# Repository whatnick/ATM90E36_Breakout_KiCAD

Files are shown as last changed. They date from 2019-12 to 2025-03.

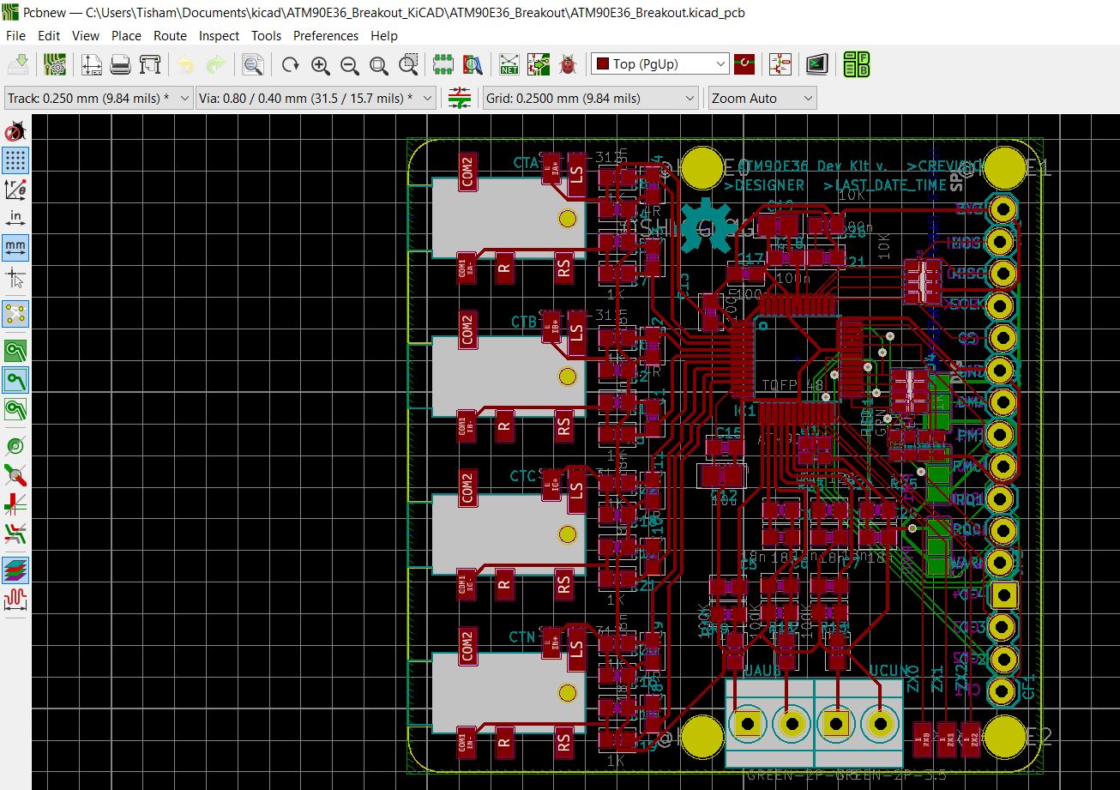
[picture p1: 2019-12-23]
doc/eagle_pcb_import.JPG

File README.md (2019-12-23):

# ATM90E3x Breakout / Devkit

Basic PCB for driver development and experimenting with the the ATM90E3x series of energy monitor ASICS.
This is the KiCAD port of the original [Eagle PCB](https://github.com/whatnick/ATM90E36_Breakout).

Arduino Drivers are available [here](https://github.com/whatnick/ATM90E32_Arduino), maintained by [CircuitSetup](https://github.com/CircuitSetup). Also checkout the [Split Single-phase Energy Monitor](https://github.com/CircuitSetup/Split-Single-Phase-Energy-Meter).

## Features
- x4 3.5mm Stereo Jacks for 3-phase + Neutral current clamps
- 12v AC 3-phase transformer input for voltage measurement
- All pins broken out for deep integration including DMA mode for ATM90E36

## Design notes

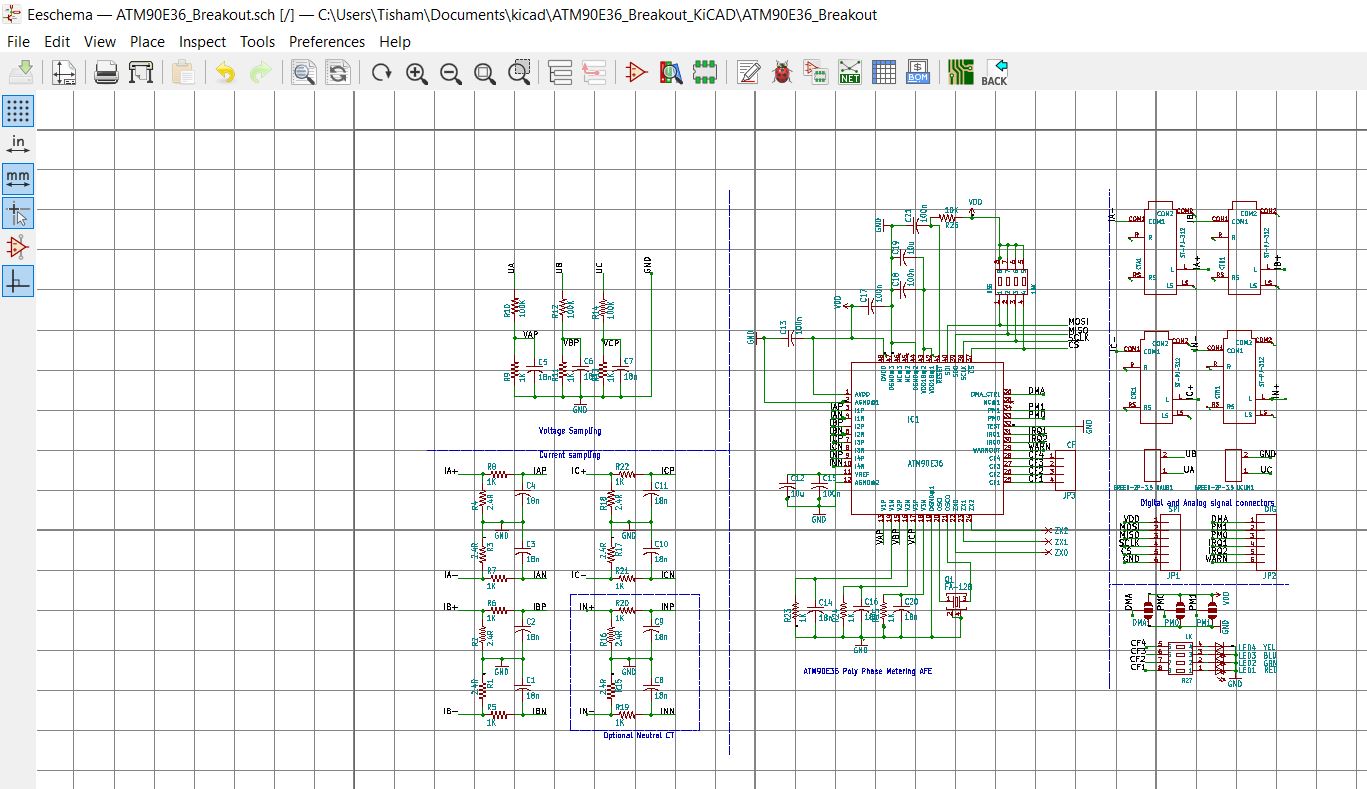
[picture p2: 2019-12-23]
doc/eagle_schema_import.JPG

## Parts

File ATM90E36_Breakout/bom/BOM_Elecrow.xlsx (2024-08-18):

*Reference | *Manufacturer Part number | *QTY | *Original | Description | Purchase Link
C13, C15, C17, C18, C21 | C0603C104K5RAC3190 | 5 | N | 100n
C1, C2, C3, C4, C5, C6, C7, C8, C9, C10, C11, C14, C16, C20 | C0603C183K5RACTU | 14 | N | 18n
C12, C19 | GRM21BR61E106MA73L | 2 | N | 10u
R1, R2, R3, R4, R15, R16, R17, R18 | CRL0603-FW-2R40ELF | 8 | N | 2.4R
R26 | RC0201JR-0710KL | 1 | N | 10K
R10, R12, R14 | RC0603FR-07100KL | 3 | N | 100K
R5, R6, R7, R8, R9, R11, R13, R19, R20, R21, R22, R23, R24, R25 | RT0603FRE071KL | 14 | N | 1K
R36 | YC164-JR-0710KL | 1 | N | 10K
R27 | YC164-JR-071KL | 1 | N | 1K
IC1 | ATM90E36A-AU-R | 1 | Y | ATM90E36A-AU-R
UAUB1, UCUN1 | 20020327-C021B01LF | 2 | N | GREEN-2P-3.5
Q1 | ECS-160-10-36-CKM-TR | 1 | Y | FA-128
LED1, LED2, LED3, LED4 | LTST-C193KRKT-5A | 4 | N | RED
CTA1, CTB1, CTC1, CTN1 | SJ-3523-SMT-TR | 4 | Y | AudioJack3

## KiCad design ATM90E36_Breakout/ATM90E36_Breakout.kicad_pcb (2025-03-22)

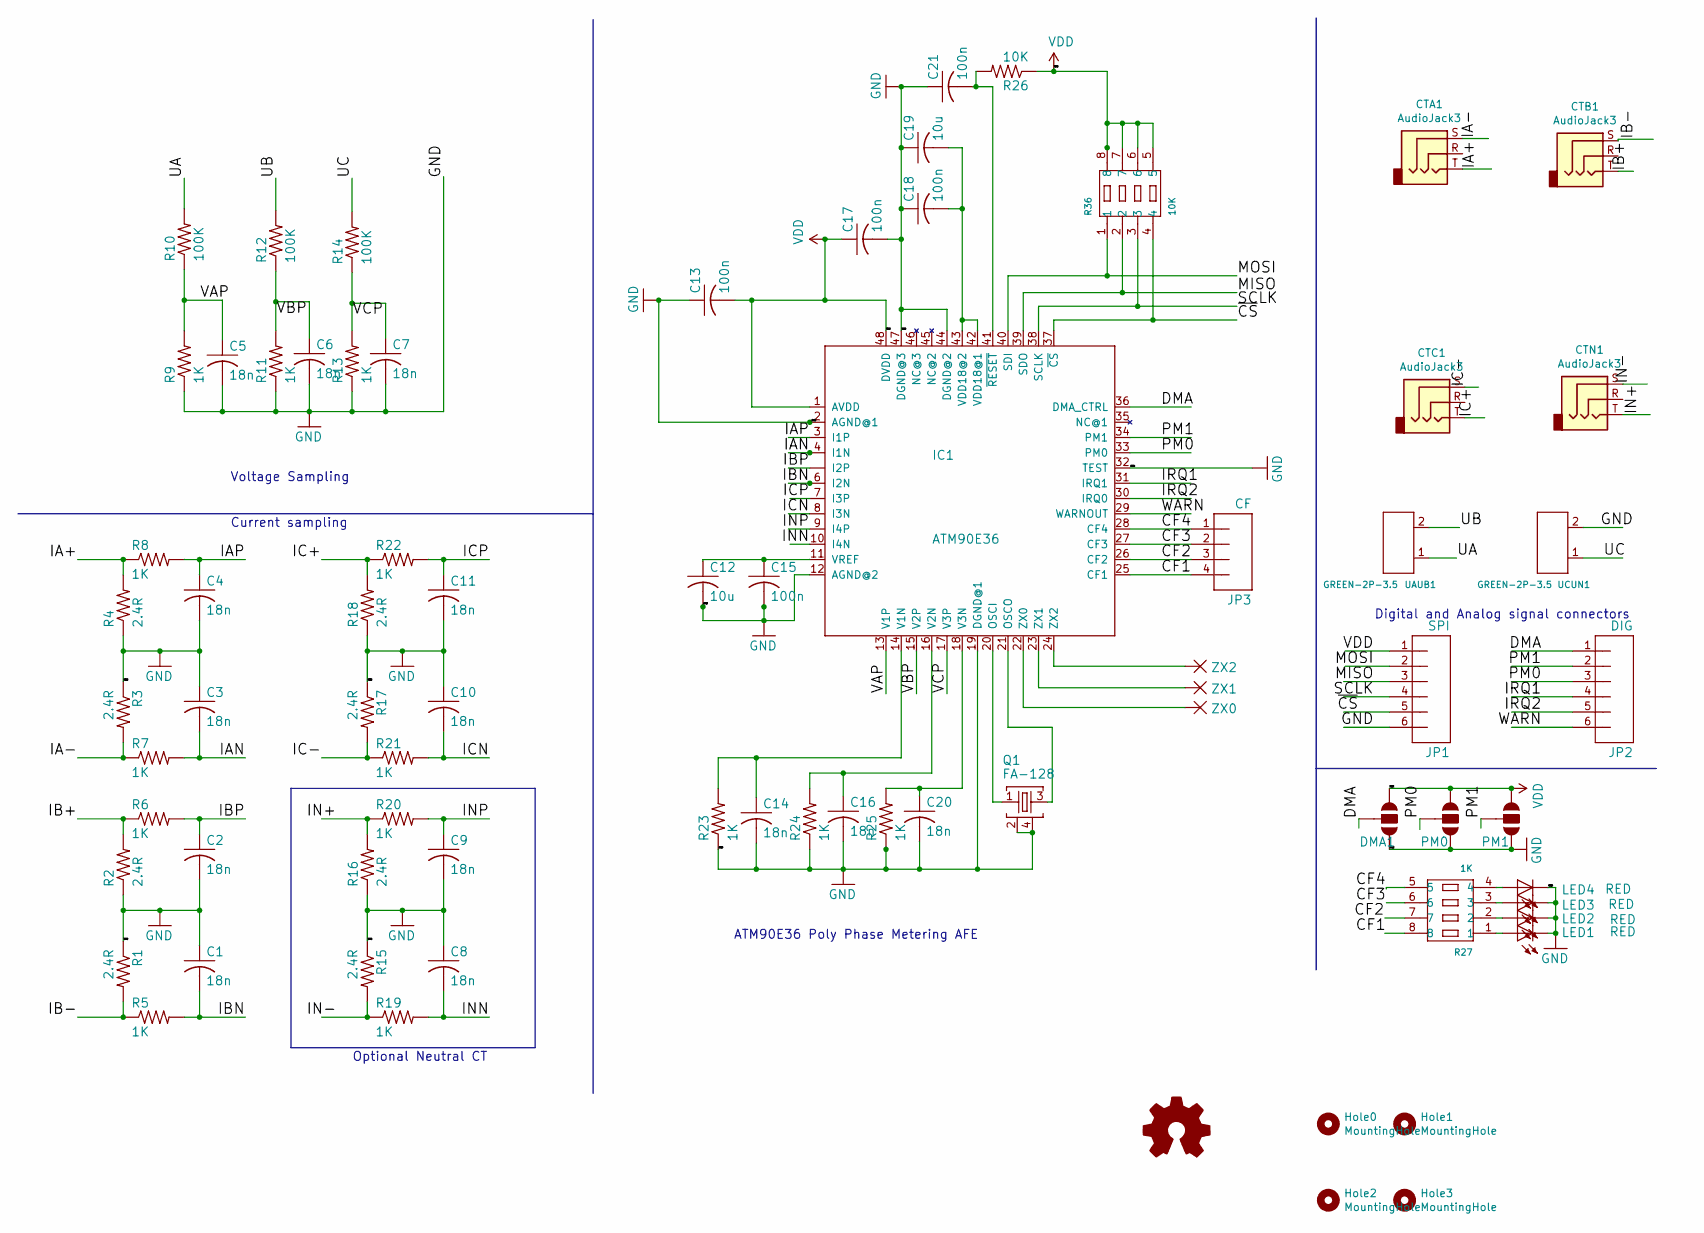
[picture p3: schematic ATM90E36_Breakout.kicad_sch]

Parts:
C1, C2, C3, C4, C5, C6, C7, C8, C9, C10, C11, C14, C16, C20: 18n; C0603
C12, C19: 10u; C0805
C13, C15, C17, C18, C21: 100n; C0603
CTA1: AudioJack3; Jack_3.5mm_CUI_SJ-3523-SMT_Horizontal
CTB1: AudioJack3; Jack_3.5mm_CUI_SJ-3523-SMT_Horizontal
CTC1: AudioJack3; Jack_3.5mm_CUI_SJ-3523-SMT_Horizontal
CTN1: AudioJack3; Jack_3.5mm_CUI_SJ-3523-SMT_Horizontal
DMA1: JUMPER-PAD-3-NOFULL_BOX_SILK; PAD-JUMPER-3-NO_YES_SILK_FULL_BOX
Hole0, Hole1, Hole2, Hole3: MountingHole; MountingHole_2.2mm_M2
IC1: ATM90E36; TQFP48
JP1: SPI; 1X06_LOCK
JP2: DIG; 1X06_LOCK
JP3: CF; 1X04_LOCK
LED1, LED2, LED3, LED4: RED; CHIP-LED0603
LOGO1: Logo_Open_Hardware_Small; OSHW-LOGO-M
PM0, PM1: JUMPER-PAD-3-NOFULL_BOX_SILK; PAD-JUMPER-3-NO_YES_SILK_FULL_BOX
Q1: FA-128
R1, R2, R3, R4, R15, R16, R17, R18: 2.4R; R0603
R5, R6, R7, R8, R9, R11, R13, R19, R20, R21, R22, R23, R24, R25: 1K; R0603
R10, R12, R14: 100K; R0603
R26: 10K; R0603
R27: 1K; RA1206-8
R36: 10K; RA1206-8
UAUB1: GREEN-2P-3.5; H2-3.5-7.0X7.0MM
UCUN1: GREEN-2P-3.5; H2-3.5-7.0X7.0MM
ZX0, ZX1, ZX2: ZX; SMD1,27-2,54

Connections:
/CF1: IC1.25 (CF1), JP3.4, R27.8
/CF2: IC1.26 (CF2), JP3.3, R27.7
/CF3: IC1.27 (CF3), JP3.2, R27.6
/CF4: IC1.28 (CF4), JP3.1, R27.5
/DMA: DMA1.2, IC1.36 (DMA_CTRL), JP2.1
/IA+: CTA1.T, R4.2, R8.1
/IA-: CTA1.S, R3.2, R7.1
/IAN: C3.2, IC1.4 (I1N), R7.2
/IAP: C4.1, IC1.3 (I1P), R8.2
/IB+: CTB1.T, R2.2, R6.1
/IB-: CTB1.S, R1.2, R5.1
/IBN: C1.2, IC1.6 (I2N), R5.2
/IBP: C2.1, IC1.5 (I2P), R6.2
/IC+: CTC1.T, R18.2, R22.1
/IC-: CTC1.S, R17.2, R21.1
/ICN: C10.2, IC1.8 (I3N), R21.2
/ICP: C11.1, IC1.7 (I3P), R22.2
/IN+: CTN1.T, R16.2, R20.1
/IN-: CTN1.S, R15.2, R19.1
/INN: C8.2, IC1.10 (I4N), R19.2
/INP: C9.1, IC1.9 (I4P), R20.2
/IRQ1: IC1.31 (IRQ1), JP2.4
/IRQ2: IC1.30 (IRQ0), JP2.5
/MISO: IC1.39 (SDO), JP1.3, R36.2
/MOSI: IC1.40 (SDI), JP1.2, R36.1
/PM0: IC1.33 (PM0), JP2.3, PM0.2
/PM1: IC1.34 (PM1), JP2.2, PM1.2
/SCLK: IC1.38 (SCLK), JP1.4, R36.3
/UA: R10.2, UAUB1.1
/UB: R12.2, UAUB1.2
/UC: R14.2, UCUN1.1
/VAP: C5.1, IC1.13 (V1P), R9.2, R10.1
/VBP: C6.1, IC1.15 (V2P), R11.2, R12.1
/VCP: C7.1, IC1.17 (V3P), R13.2, R14.1
/WARN: IC1.29 (WARNOUT), JP2.6
/~CS: IC1.37 (~CS), JP1.5, R36.4
GND: C1.1, C2.2, C3.1, C4.2, C5.2, C6.2, C7.2, C8.1, C9.2, C10.1, C11.2, C12.2, C13.1, C14.2, C15.2, C16.2, C17.2, C18.1, C19.1, C20.2, C21.1, DMA1.3, IC1.2 (AGND@1), IC1.12 (AGND@2), IC1.19 (DGND@1), IC1.32 (TEST), IC1.44 (DGND@2), IC1.47 (DGND@3), JP1.6, LED1.C, LED2.C, LED3.C, LED4.C, PM0.3, PM1.3, Q1.2, Q1.4, R1.1, R2.1, R3.1, R4.1, R9.1, R11.1, R13.1, R15.1, R16.1, R17.1, R18.1, R23.1, R24.1, R25.1, UCUN1.2
unnamed: C12.1, C15.1, IC1.11 (VREF)
unnamed: C14.1, IC1.14 (V1N), R23.2
unnamed: C16.1, IC1.16 (V2N), R24.2
unnamed: C18.2, C19.2, IC1.42 (VDD18@1), IC1.43 (VDD18@2)
unnamed: C20.1, IC1.18 (V3N), R25.2
unnamed: C21.2, IC1.41 (~RESET), R26.2
unnamed: IC1.20 (OSCI), Q1.1
unnamed: IC1.21 (OSCO), Q1.3
unnamed: IC1.22 (ZX0), ZX0.1
unnamed: IC1.23 (ZX1), ZX1.1
unnamed: IC1.24 (ZX2), ZX2.1
unnamed: LED1.A, R27.1
unnamed: LED2.A, R27.2
unnamed: LED3.A, R27.3
unnamed: LED4.A, R27.4
VDD: C13.2, C17.1, DMA1.1, IC1.1 (AVDD), IC1.48 (DVDD), JP1.1, PM0.1, PM1.1, R26.1, R36.5, R36.6, R36.7, R36.8

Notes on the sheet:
ATM90E36 Poly Phase Metering AFE
Optional Neutral CT
Voltage Sampling
Current sampling
Digital and Analog signal connectors

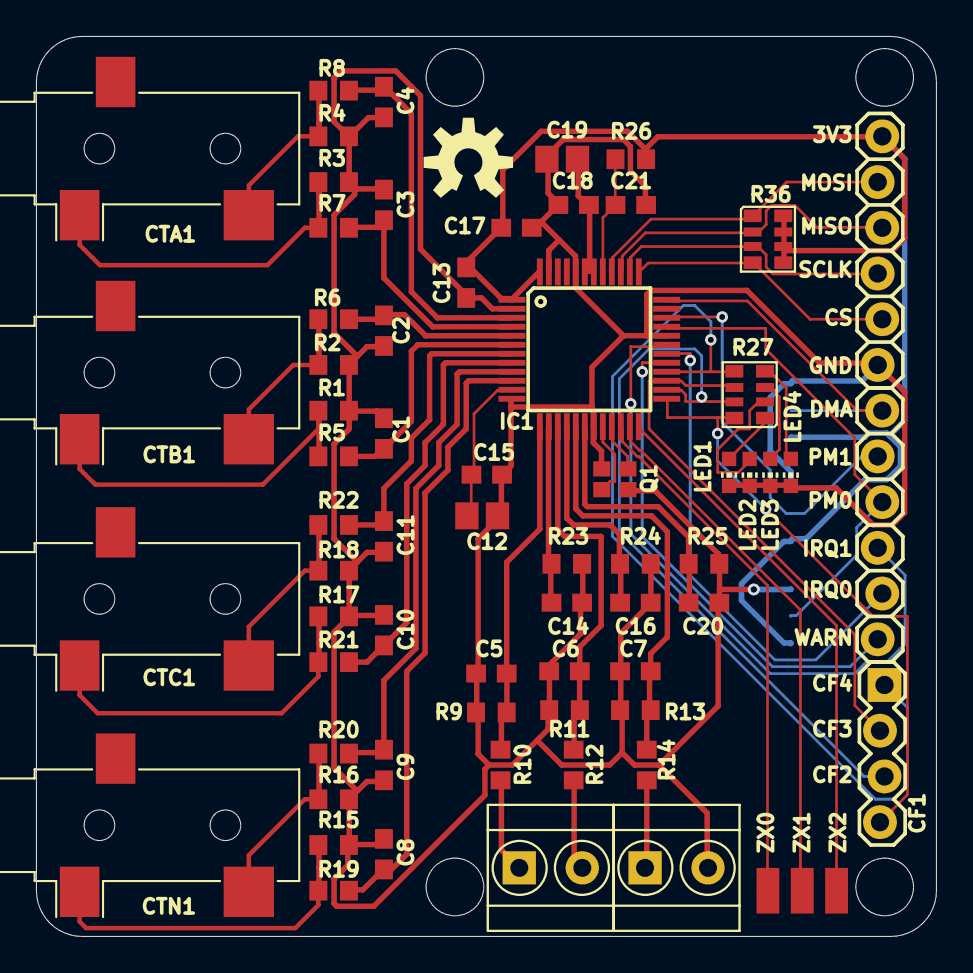
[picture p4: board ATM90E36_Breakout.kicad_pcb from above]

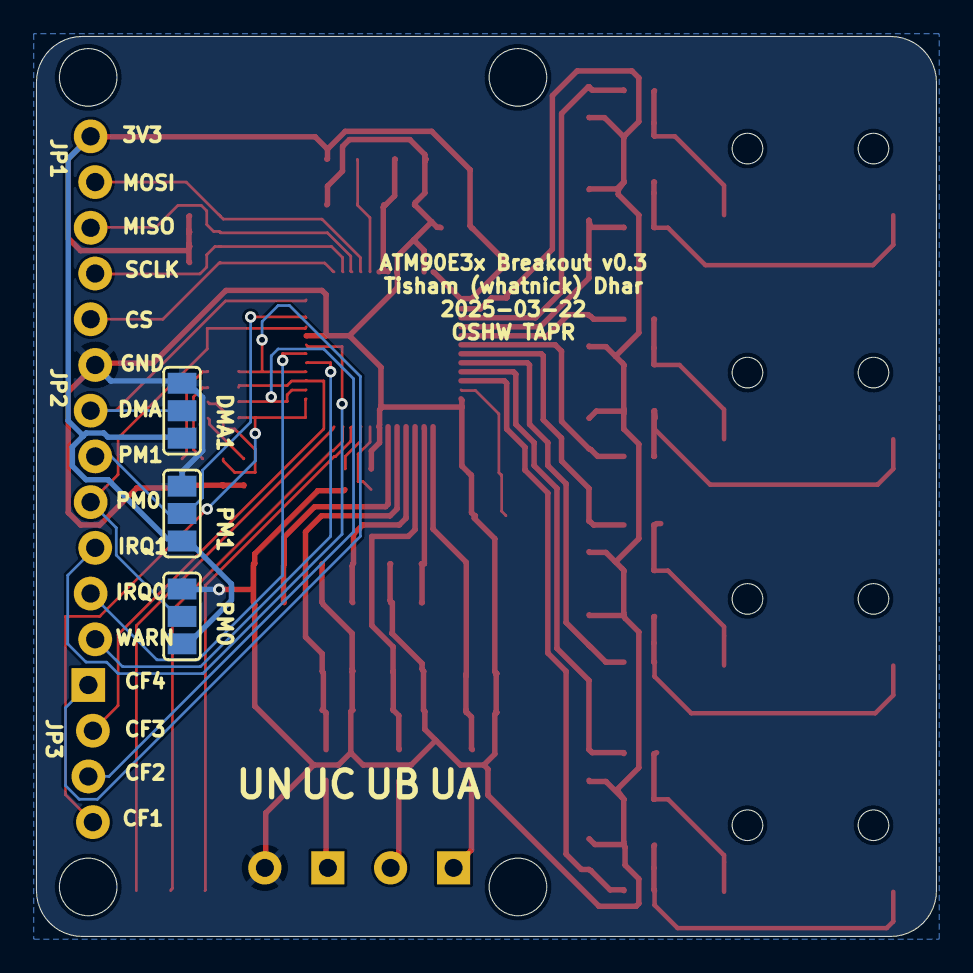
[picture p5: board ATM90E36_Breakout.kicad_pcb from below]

Board: 2 copper layers, 50.0 x 50.0 mm, 75 parts (3 on the bottom side), 53 nets.

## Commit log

2019-12-23 Initial Import from Eagle
    [ATM90E36_Breakout.kicad_pcb, ATM90E36_Breakout.sch]
2019-12-23 Fix references and SCH/PCB linkage
    [ATM90E36_Breakout.kicad_pcb]
2019-12-23 Remove edge cuts from parts to fix board outline
    [ATM90E36_Breakout.kicad_pcb]
2019-12-25 Fix up silk screens
    [ATM90E36_Breakout.kicad_pcb, ATM90E36_Breakout.sch]
2019-12-30 Add full BOM and Gerbers
    [ATM90E36_Breakout-B_Mask.gbs, ATM90E36_Breakout-B_Paste.gbp, ATM90E36_Breakout-B_SilkS.gbo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]
2019-12-31 Add BOM and dimensions for production prep
    [ATM90E36_Breakout.kicad_pcb, ATM90E36_Breakout.xlsx]
2020-01-04 Update parts for availability
    [ATM90E36_Breakout.sch, ATM90E36_Breakout.xlsx]
2020-01-08 Updated Stereojacks to mainstream ones
    [ATM90E36_Breakout-B_Mask.gbs, ATM90E36_Breakout-B_Paste.gbp, ATM90E36_Breakout-B_SilkS.gbo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]
2020-01-08 Updated Excel BOM
    [ATM90E36_Breakout.xlsx]
2020-02-20 Fix BOM part
    [ATM90E36_Breakout.sch]
2024-08-18 Upgrade to KiCAD 7 and order from Elecrow
    [ATM90E36_Breakout.kicad_pcb, ATM90E36_Breakout.kicad_sch, BOM_Elecrow.xlsx]
2025-03-22 Update silkscreen to avoid wiring confusion
    [ATM90E36_Breakout-B_Mask.gbs, ATM90E36_Breakout-B_Paste.gbp, ATM90E36_Breakout-B_Silkscreen.gbo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]
2025-03-22 deleted old outputs
    [ATM90E36_Breakout-B_SilkS.gbo, ATM90E36_Breakout-F_SilkS.gto, ATM90E36_Breakout-all-pos.csv]
